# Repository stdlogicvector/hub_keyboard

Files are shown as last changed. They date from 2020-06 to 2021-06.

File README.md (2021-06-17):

# HUB Keyboard

A custom built 80% keyboard with an OLED and an integrated USB hub.

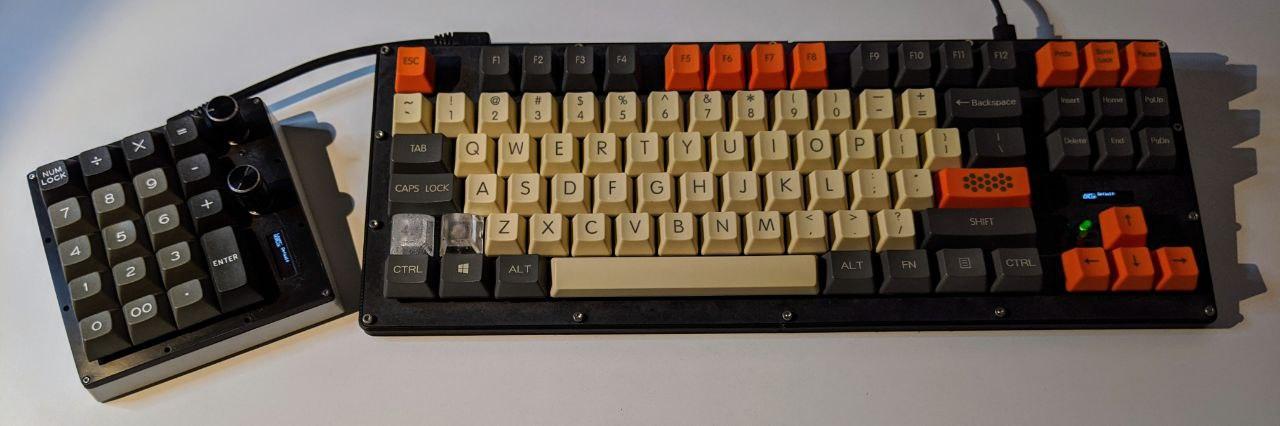
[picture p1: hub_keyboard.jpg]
HUB Keyboard with Numpad attached via USB


(The Numpad can be found here.)

## Circuit Board

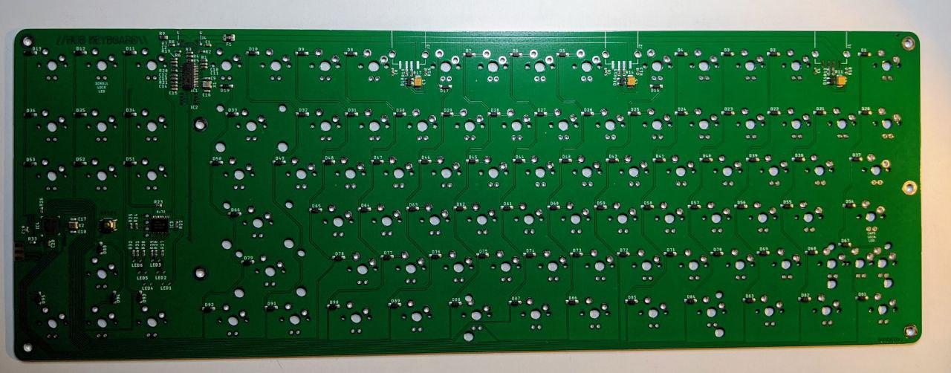
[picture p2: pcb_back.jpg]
Populated Circit Board - Bottom Side


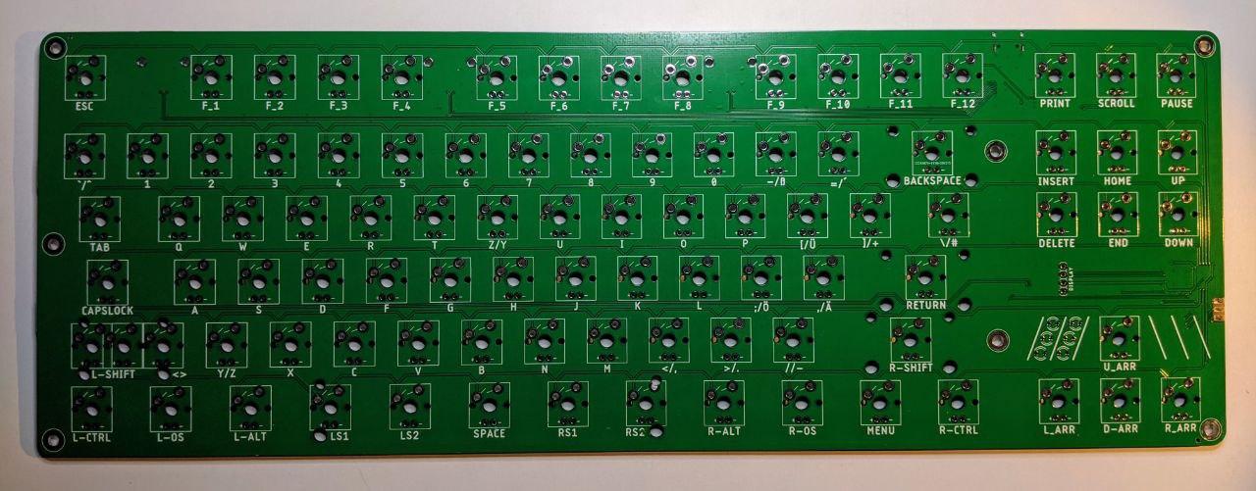
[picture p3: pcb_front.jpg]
Populated Circit Board - Top Side


The circuit board is designed in Eagle.
For easy manufacturing, the gerber-files and SMT production files are included.

The BOM and SMT placement file (CPL) are formatted for use with JLCPCB.

Apart from the keys, display, and the USB-connector all parts can be populated by JLCPCB.
The schematic contains the LCSC partnumbers in the attributes of each part.

### JLCPCB Configuration

If you want to order PCBs from JLC-PCB with the provided gerber-files,
use the following settings after uploading the zipped gerber folder:

* Layers: 2
* Dimension: 362mm x 128.5mm
* PCB Color: Choose what you want
* PCB Thickness: 1.6
* Impedance: no
* Surface Finish: HASL(with lead) (ENIG is also OK)
* Copper Weight: 1
* Gold Fingers: No
* Material Details: FR4-Standard Tg 130-140C
* Panel By JLCPCB: No
* Flying Probe Test: Fully Test
* Castellated Holes: no
* Different Design: 1
* Remove Order Number: Choose what you want

5 PCBs without assembly cost about 17.35€ or $19.60.

If you want to have the SMT parts populated, choose "SMT Assembly" and select "Bottom Layer".

When asked for the BOM and CPL file, upload the provided files.

Assembly and parts for 5 PCBs costs about 45.50€ or $55.90.

### Keys

All keys compatible with Cherry MX 2 or 3 pin should fit the board.
There a mounting holes for the US-layout (with 2.25U Left Shift) and the EU-layout (with <> next to 1.25U Left Shift).
The Spacebar can also be replaced by up 5 individual keys.

### Display

The display is an 0.91" 128x32 SPI OLED module like [this](https://www.ebay.com/itm/312892164528). They are all over ebay and aliexpress.

### Misc Parts

The USB Connectors can be found on Digikey, but you can substitute others with the same pad layout.#

* USB-C : [Digikey](https://www.digikey.com/short/zm17vb)
* USB-A : [Digikey](https://www.digikey.com/short/zm1tcc)

## QMK Configuration

The folder qmk_config contains the configuration and code to build QMK for the HUB-Keyboard.
Just put this folder in qmk/keyboards and run

```
make hub_keyboard/v1:default
```	
	
## Plate & Case

Plate and Case are available as DXF and STL files. The Case also comes in two halves for easier printing. The DXF contains lines for both layout options at the left shift key. Delete what you don't need before cutting.

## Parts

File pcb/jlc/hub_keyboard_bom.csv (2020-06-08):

Comment | Designator | Footprint | LCSC
1.1A | F1 | 1210 | C70100
1M | R8, R10, R13, R16 | 0603 | C22935
1N4148 | D1, D2, D3, D4, D5, D6, D7, D8, D9, D10, D11, D12, D13, D15, D17, D19, D20, D21, D22, D23, D24, D25, D26, D27, D28, D29, D30, D31, D32, D33, D34, D35, D36, D37, D38, D39, D40, D41, D42, D43, D44, D45, D46, D47, D48, D49, D50, D51, D52, D53, D54, D55, D56, D57, D58, D59, D60, D61, D62, D63, D64, D65, D66, D67, D68, D69, D70, D71, D72, D73, D74, D75, D76, D77, D78, D79, D80, D81, D82, D83, D84, D85, D86, D87, D88, D89, D90, D91, D92, D93, D94, D95 | SOD123 | C81598
1k | R22, R23, R26, R27, R28, R29, R30, R31, R32 | 0603 | C21190
1u | C20 | 0603 | C15849
2k7 | R1 | 0603 | C13167
5k1 | R2, R6 | 0603 | C23186
10k | R7, R20, R21, R33 | 0603 | C25804
10n | C14 | 0603 | C57112
10n | C1, C4, C6, C8 | 0603 | C84709
10u | C11, C12, C13 | 0603 | C19702
12MHz | X1 | SMD-3225_4P | C9002
12pF | C9, C16, C17, C18 | 0603 | C38523
16MHz | X2 | SMD-3225_4P | C13738
20k | R5, R24, R25 | 0603 | C4184
22R | R3, R4, R11, R12, R14, R15, R17, R18 | 0603 | C23345
100k | R19 | 0603 | C25803
100nF | C2, C10, C15, C19 | 0603 | C14663
100uF | C3, C5, C7 | 3528 | C16133
FE1.1S | IC1 | SSOP-28 | C9359
Ferrite | R9 | 0805 | C44361
PCF8574APWR | IC3 | TSSOP-20 | C94361
PRTR5V0U2X | D14, D16, D18 | SOT-143 | C384891
ATMEGA32U4-MU | IC4 | QFN-44_EP_7x7x0.5P | C112161
SPST-SMD-5.2 | RESET | SMD-5.2 | C318884
24LC024SN | IC2 | 24LC024SN | C184083

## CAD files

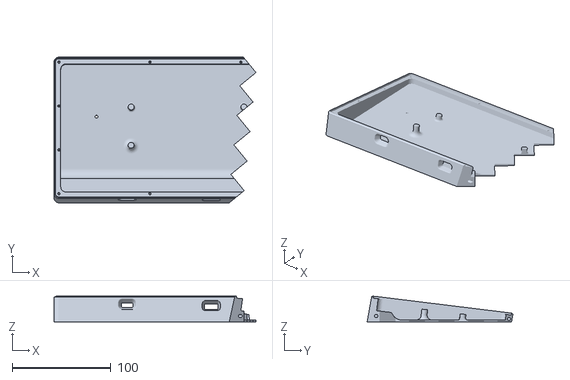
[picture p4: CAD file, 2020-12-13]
cad/Case_3D_right.stl
204.2 x 147.4 x 26.2

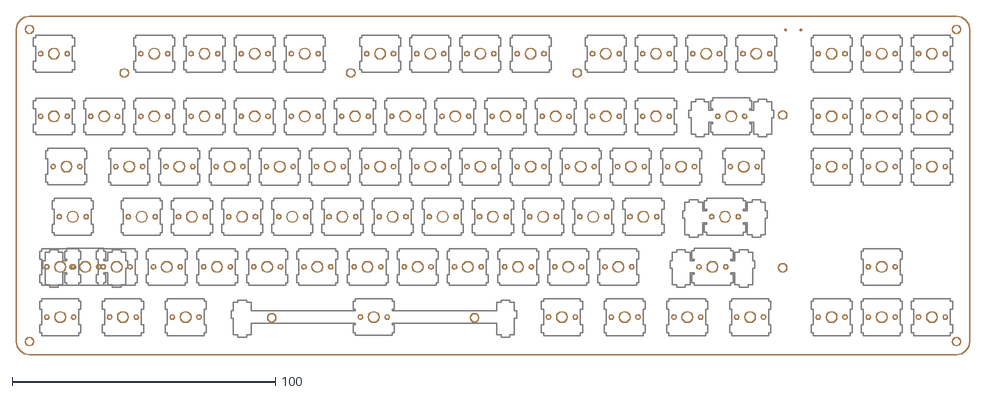
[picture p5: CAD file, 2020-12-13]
cad/keyboard_plate.dxf
362.0 x 128.5

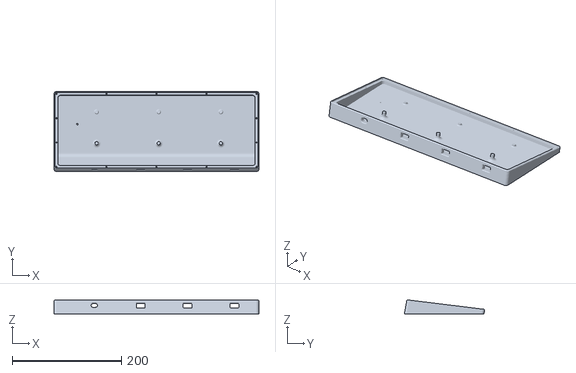
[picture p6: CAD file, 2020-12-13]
cad/Case_3d.stl
376.0 x 147.4 x 26.2

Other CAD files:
cad/Case_3D_left.stl

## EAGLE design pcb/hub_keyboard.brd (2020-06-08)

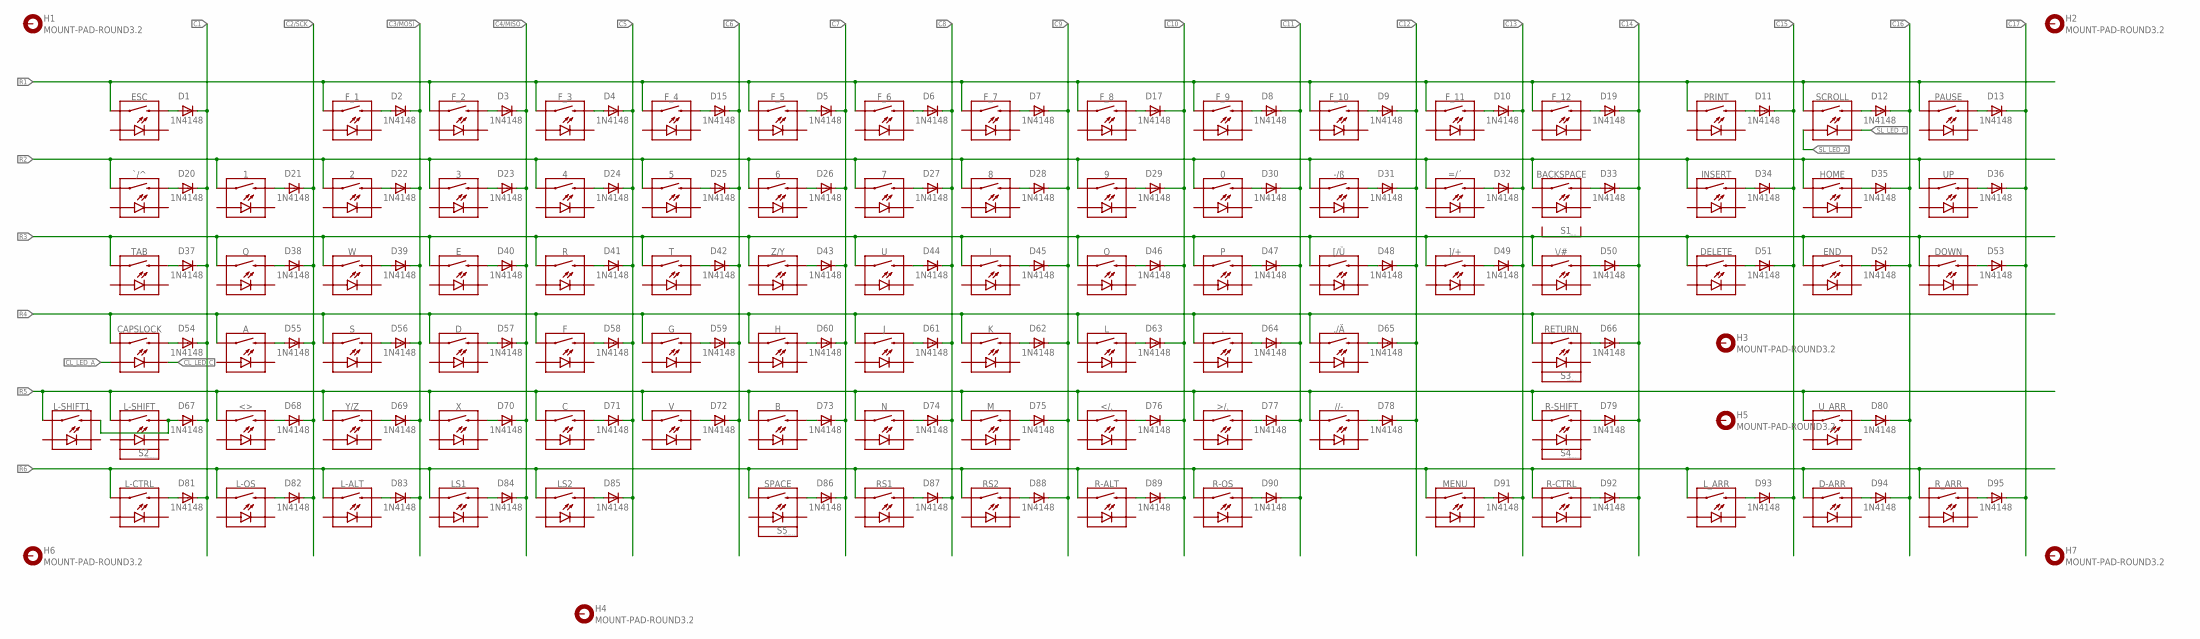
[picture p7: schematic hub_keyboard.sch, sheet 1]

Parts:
0, 1, 2, 3, 4, 5, 6, 7, 8, 9, .: MECHANICAL-KEYBOARD1U; CHERRY-MX-LED-1U
,/Ä: MECHANICAL-KEYBOARD1U; CHERRY-MX-LED-1U
-/ß: MECHANICAL-KEYBOARD1U; CHERRY-MX-LED-1U
//-: MECHANICAL-KEYBOARD1U; CHERRY-MX-LED-1U
</,: MECHANICAL-KEYBOARD1U; CHERRY-MX-LED-1U
<>: MECHANICAL-KEYBOARD1U; CHERRY-MX-LED-1U
=/´: MECHANICAL-KEYBOARD1U; CHERRY-MX-LED-1U
>/.: MECHANICAL-KEYBOARD1U; CHERRY-MX-LED-1U
A: MECHANICAL-KEYBOARD1U; CHERRY-MX-LED-1U
B: MECHANICAL-KEYBOARD1U; CHERRY-MX-LED-1U
BACKSPACE: MECHANICAL-KEYBOARD2U; CHERRY-MX-LED-1X2U
C: MECHANICAL-KEYBOARD1U; CHERRY-MX-LED-1U
CAPSLOCK: MECHANICAL-KEYBOARD1.75U; CHERRY-MX-LED-1.75U
D: MECHANICAL-KEYBOARD1U; CHERRY-MX-LED-1U
D1, D2, D3, D4, D5, D6, D7, D8, D9, D10, D11, D12, D13, D15, D17, D19, D20, D21, D22, D23, D24, D25, D26, D27, D28, D29, D30, D31, D32, D33, D34, D35, D36, D37, D38, D39, D40, D41, D42, D43, D44, D45, D46, D47, D48, D49, D50, D51, D52, D53, D54, D55, D56, D57, D58, D59, D60, D61, D62, D63, D64, D65, D66, D67, D68, D69, D70, D71, D72, D73, D74, D75, D76, D77, D78, D79, D80, D81, D82, D83, D84, D85, D86, D87, D88, D89, D90, D91, D92, D93, D94, D95: 1N4148; SOD123; LCSC C81598
D-ARR: MECHANICAL-KEYBOARD1U; CHERRY-MX-LED-1U
DELETE: MECHANICAL-KEYBOARD1U; CHERRY-MX-LED-1U
DOWN: MECHANICAL-KEYBOARD1U; CHERRY-MX-LED-1U
E: MECHANICAL-KEYBOARD1U; CHERRY-MX-LED-1U
END: MECHANICAL-KEYBOARD1U; CHERRY-MX-LED-1U
ESC: MECHANICAL-KEYBOARD1U; CHERRY-MX-LED-1U
F: MECHANICAL-KEYBOARD1U; CHERRY-MX-LED-1U
F_1, F_2, F_3, F_4, F_5, F_6, F_7, F_8, F_9, F_10, F_11, F_12: MECHANICAL-KEYBOARD1U; CHERRY-MX-LED-1U
G: MECHANICAL-KEYBOARD1U; CHERRY-MX-LED-1U
H: MECHANICAL-KEYBOARD1U; CHERRY-MX-LED-1U
H1, H2, H3, H4, H5, H6, H7: MOUNT-PAD-ROUND3.2; 3,2-PAD
HOME: MECHANICAL-KEYBOARD1U; CHERRY-MX-LED-1U
I: MECHANICAL-KEYBOARD1U; CHERRY-MX-LED-1U
INSERT: MECHANICAL-KEYBOARD1U; CHERRY-MX-LED-1U
J: MECHANICAL-KEYBOARD1U; CHERRY-MX-LED-1U
K: MECHANICAL-KEYBOARD1U; CHERRY-MX-LED-1U
L: MECHANICAL-KEYBOARD1U; CHERRY-MX-LED-1U
L-ALT: MECHANICAL-KEYBOARD1.25U; CHERRY-MX-LED-1.25U
L-CTRL: MECHANICAL-KEYBOARD1.25U; CHERRY-MX-LED-1.25U
L-OS: MECHANICAL-KEYBOARD1.25U; CHERRY-MX-LED-1.25U
L-SHIFT: MECHANICAL-KEYBOARD2.25U; CHERRY-MX-LED-1X2.25
L-SHIFT1: MECHANICAL-KEYBOARD1.25U; CHERRY-MX-LED-1.25U
LS1, LS2: MECHANICAL-KEYBOARD1.25U; CHERRY-MX-LED-1.25U
L_ARR: MECHANICAL-KEYBOARD1U; CHERRY-MX-LED-1U
M: MECHANICAL-KEYBOARD1U; CHERRY-MX-LED-1U
MENU: MECHANICAL-KEYBOARD1.25U; CHERRY-MX-LED-1.25U
N: MECHANICAL-KEYBOARD1U; CHERRY-MX-LED-1U
O: MECHANICAL-KEYBOARD1U; CHERRY-MX-LED-1U
P: MECHANICAL-KEYBOARD1U; CHERRY-MX-LED-1U
PAUSE: MECHANICAL-KEYBOARD1U; CHERRY-MX-LED-1U
PRINT: MECHANICAL-KEYBOARD1U; CHERRY-MX-LED-1U
Q: MECHANICAL-KEYBOARD1U; CHERRY-MX-LED-1U
R: MECHANICAL-KEYBOARD1U; CHERRY-MX-LED-1U
R-ALT: MECHANICAL-KEYBOARD1.25U; CHERRY-MX-LED-1.25U
R-CTRL: MECHANICAL-KEYBOARD1.25U; CHERRY-MX-LED-1.25U
R-OS: MECHANICAL-KEYBOARD1.25U; CHERRY-MX-LED-1.25U
R-SHIFT: MECHANICAL-KEYBOARD2.75U; CHERRY-MX-LED-1X2.75
RETURN: MECHANICAL-KEYBOARD2.25U; CHERRY-MX-LED-1X2.25
RS1, RS2: MECHANICAL-KEYBOARD1.25U; CHERRY-MX-LED-1.25U
R_ARR: MECHANICAL-KEYBOARD1U; CHERRY-MX-LED-1U
S: MECHANICAL-KEYBOARD1U; CHERRY-MX-LED-1U
S1: STABILIZER-1X2U; STABILIZER_1X2U
S2, S3: STABILIZER-1X2.25U; STABILIZER_1X2.25U
S4: STABILIZER-1X2.75U; STABILIZER_1X2.75U
S5: STABILIZER-1X6.25U; STABILIZER_1X6.25U
SCROLL: MECHANICAL-KEYBOARD1U; CHERRY-MX-LED-1U
SPACE: MECHANICAL-KEYBOARD6.25U; CHERRY-MX-LED-1X6.25
T: MECHANICAL-KEYBOARD1U; CHERRY-MX-LED-1U
TAB: MECHANICAL-KEYBOARD1.5U; CHERRY-MX-LED-1.5U
U: MECHANICAL-KEYBOARD1U; CHERRY-MX-LED-1U
UP: MECHANICAL-KEYBOARD1U; CHERRY-MX-LED-1U
U_ARR: MECHANICAL-KEYBOARD1U; CHERRY-MX-LED-1U
V: MECHANICAL-KEYBOARD1U; CHERRY-MX-LED-1U
W: MECHANICAL-KEYBOARD1U; CHERRY-MX-LED-1U
X: MECHANICAL-KEYBOARD1U; CHERRY-MX-LED-1U
Y/Z: MECHANICAL-KEYBOARD1U; CHERRY-MX-LED-1U
Z/Y: MECHANICAL-KEYBOARD1U; CHERRY-MX-LED-1U
[/Ü: MECHANICAL-KEYBOARD1U; CHERRY-MX-LED-1U
\\/#: MECHANICAL-KEYBOARD1.5U; CHERRY-MX-LED-1.5U
]/+: MECHANICAL-KEYBOARD1U; CHERRY-MX-LED-1U
`/^: MECHANICAL-KEYBOARD1U; CHERRY-MX-LED-1U

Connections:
C1: D1.C, D20.C, D37.C, D54.C, D67.C, D81.C; also elsewhere on the board
C2/SCK: D21.C, D38.C, D55.C, D68.C, D82.C; also elsewhere on the board
C3/MOSI: D2.C, D22.C, D39.C, D56.C, D69.C, D83.C; also elsewhere on the board
C4/MISO: D3.C, D23.C, D40.C, D57.C, D70.C, D84.C; also elsewhere on the board
C5: D4.C, D24.C, D41.C, D58.C, D71.C, D85.C; also elsewhere on the board
C6: D15.C, D25.C, D42.C, D59.C, D72.C; also elsewhere on the board
C7: D5.C, D26.C, D43.C, D60.C, D73.C, D86.C; also elsewhere on the board
C8: D6.C, D27.C, D44.C, D61.C, D74.C, D87.C; also elsewhere on the board
C9: D7.C, D28.C, D45.C, D62.C, D75.C, D88.C; also elsewhere on the board
C10: D17.C, D29.C, D46.C, D63.C, D76.C, D89.C; also elsewhere on the board
C11: D8.C, D30.C, D47.C, D64.C, D77.C, D90.C; also elsewhere on the board
C12: D9.C, D31.C, D48.C, D65.C, D78.C; also elsewhere on the board
C13: D10.C, D32.C, D49.C, D91.C; also elsewhere on the board
C14: D19.C, D33.C, D50.C, D66.C, D79.C, D92.C; also elsewhere on the board
C15: D11.C, D34.C, D51.C, D93.C; also elsewhere on the board
C16: D12.C, D35.C, D52.C, D80.C, D94.C; also elsewhere on the board
C17: D13.C, D36.C, D53.C, D95.C; also elsewhere on the board
CL_LED_A: CAPSLOCK.A; also elsewhere on the board
CL_LED_C: CAPSLOCK.K (C); also elsewhere on the board
unnamed: D11.A, PRINT.S2 (2)
unnamed: D34.A, INSERT.S2 (2)
unnamed: D51.A, DELETE.S2 (2)
unnamed: D12.A, SCROLL.S2 (2)
unnamed: D35.A, HOME.S2 (2)
unnamed: D93.A, L_ARR.S2 (2)
unnamed: D52.A, END.S2 (2)
unnamed: D80.A, U_ARR.S2 (2)
unnamed: D94.A, D-ARR.S2 (2)
unnamed: D13.A, PAUSE.S2 (2)
unnamed: D36.A, UP.S2 (2)
unnamed: D53.A, DOWN.S2 (2)
unnamed: <>.S2 (2), D68.A
unnamed: D95.A, R_ARR.S2 (2)
unnamed: D1.A, ESC.S2 (2)
unnamed: D20.A, `/^.S2 (2)
unnamed: D37.A, TAB.S2 (2)
unnamed: CAPSLOCK.S2 (2), D54.A
unnamed: D67.A, L-SHIFT.S2 (2), L-SHIFT1.S2 (2)
unnamed: D81.A, L-CTRL.S2 (2)
unnamed: 1.S2 (2), D21.A
unnamed: D38.A, Q.S2 (2)
unnamed: A.S2 (2), D55.A
unnamed: D69.A, Y/Z.S2 (2)
unnamed: D82.A, L-OS.S2 (2)
unnamed: D2.A, F_1.S2 (2)
unnamed: 2.S2 (2), D22.A
unnamed: D39.A, W.S2 (2)
unnamed: D56.A, S.S2 (2)
unnamed: D70.A, X.S2 (2)
unnamed: D83.A, L-ALT.S2 (2)
unnamed: D3.A, F_2.S2 (2)
unnamed: 3.S2 (2), D23.A
unnamed: D40.A, E.S2 (2)
unnamed: D.S2 (2), D57.A
unnamed: C.S2 (2), D71.A
unnamed: D4.A, F_3.S2 (2)
unnamed: 4.S2 (2), D24.A
unnamed: D41.A, R.S2 (2)
unnamed: D58.A, F.S2 (2)
unnamed: D72.A, V.S2 (2)
unnamed: D15.A, F_4.S2 (2)
unnamed: 5.S2 (2), D25.A
unnamed: D42.A, T.S2 (2)
unnamed: D59.A, G.S2 (2)
unnamed: B.S2 (2), D73.A
unnamed: D86.A, SPACE.S2 (2)
unnamed: D5.A, F_5.S2 (2)
unnamed: 6.S2 (2), D26.A
unnamed: D43.A, Z/Y.S2 (2)
unnamed: D60.A, H.S2 (2)
unnamed: D74.A, N.S2 (2)
unnamed: D6.A, F_6.S2 (2)
unnamed: 7.S2 (2), D27.A
unnamed: D44.A, U.S2 (2)
unnamed: D61.A, J.S2 (2)
unnamed: D75.A, M.S2 (2)
unnamed: D7.A, F_7.S2 (2)
unnamed: 8.S2 (2), D28.A
unnamed: D45.A, I.S2 (2)
unnamed: D62.A, K.S2 (2)
unnamed: </,.S2 (2), D76.A
unnamed: D17.A, F_8.S2 (2)
unnamed: 9.S2 (2), D29.A
unnamed: D46.A, O.S2 (2)
unnamed: D63.A, L.S2 (2)
unnamed: >/..S2 (2), D77.A
unnamed: D89.A, R-ALT.S2 (2)
unnamed: D8.A, F_9.S2 (2)
unnamed: 0.S2 (2), D30.A
unnamed: D47.A, P.S2 (2)
unnamed: ..S2 (2), D64.A
unnamed: //-.S2 (2), D78.A
unnamed: D90.A, R-OS.S2 (2)
unnamed: D9.A, F_10.S2 (2)
unnamed: -/ß.S2 (2), D31.A
unnamed: D48.A, [/Ü.S2 (2)
unnamed: ,/Ä.S2 (2), D65.A
unnamed: D10.A, F_11.S2 (2)
unnamed: =/´.S2 (2), D32.A
unnamed: D49.A, ]/+.S2 (2)
unnamed: D91.A, MENU.S2 (2)
unnamed: D19.A, F_12.S2 (2)
unnamed: BACKSPACE.S2 (2), D33.A
unnamed: D50.A, \\/#.S2 (2)
unnamed: D66.A, RETURN.S2 (2)
unnamed: D79.A, R-SHIFT.S2 (2)
unnamed: D92.A, R-CTRL.S2 (2)
unnamed: D85.A, LS2.S2 (2)
unnamed: D84.A, LS1.S2 (2)
unnamed: D88.A, RS2.S2 (2)
unnamed: D87.A, RS1.S2 (2)
R1: ESC.S1 (1), F_1.S1 (1), F_2.S1 (1), F_3.S1 (1), F_4.S1 (1), F_5.S1 (1), F_6.S1 (1), F_7.S1 (1), F_8.S1 (1), F_9.S1 (1), F_10.S1 (1), F_11.S1 (1), F_12.S1 (1), PAUSE.S1 (1), PRINT.S1 (1), SCROLL.S1 (1); also elsewhere on the board
R2: 0.S1 (1), 1.S1 (1), 2.S1 (1), 3.S1 (1), 4.S1 (1), 5.S1 (1), 6.S1 (1), 7.S1 (1), 8.S1 (1), 9.S1 (1), -/ß.S1 (1), =/´.S1 (1), BACKSPACE.S1 (1), HOME.S1 (1), INSERT.S1 (1), UP.S1 (1), `/^.S1 (1); also elsewhere on the board
R3: DELETE.S1 (1), DOWN.S1 (1), E.S1 (1), END.S1 (1), I.S1 (1), O.S1 (1), P.S1 (1), Q.S1 (1), R.S1 (1), T.S1 (1), TAB.S1 (1), U.S1 (1), W.S1 (1), Z/Y.S1 (1), [/Ü.S1 (1), \\/#.S1 (1), ]/+.S1 (1); also elsewhere on the board
R4: ,/Ä.S1 (1), ..S1 (1), A.S1 (1), CAPSLOCK.S1 (1), D.S1 (1), F.S1 (1), G.S1 (1), H.S1 (1), J.S1 (1), K.S1 (1), L.S1 (1), RETURN.S1 (1), S.S1 (1); also elsewhere on the board
R5: //-.S1 (1), </,.S1 (1), <>.S1 (1), >/..S1 (1), B.S1 (1), C.S1 (1), L-SHIFT.S1 (1), L-SHIFT1.S1 (1), M.S1 (1), N.S1 (1), R-SHIFT.S1 (1), U_ARR.S1 (1), V.S1 (1), X.S1 (1), Y/Z.S1 (1); also elsewhere on the board
R6: D-ARR.S1 (1), L-ALT.S1 (1), L-CTRL.S1 (1), L-OS.S1 (1), LS1.S1 (1), LS2.S1 (1), L_ARR.S1 (1), MENU.S1 (1), R-ALT.S1 (1), R-CTRL.S1 (1), R-OS.S1 (1), RS1.S1 (1), RS2.S1 (1), R_ARR.S1 (1), SPACE.S1 (1); also elsewhere on the board
SL_LED_A: SCROLL.A; also elsewhere on the board
SL_LED_C: SCROLL.K (C); also elsewhere on the board

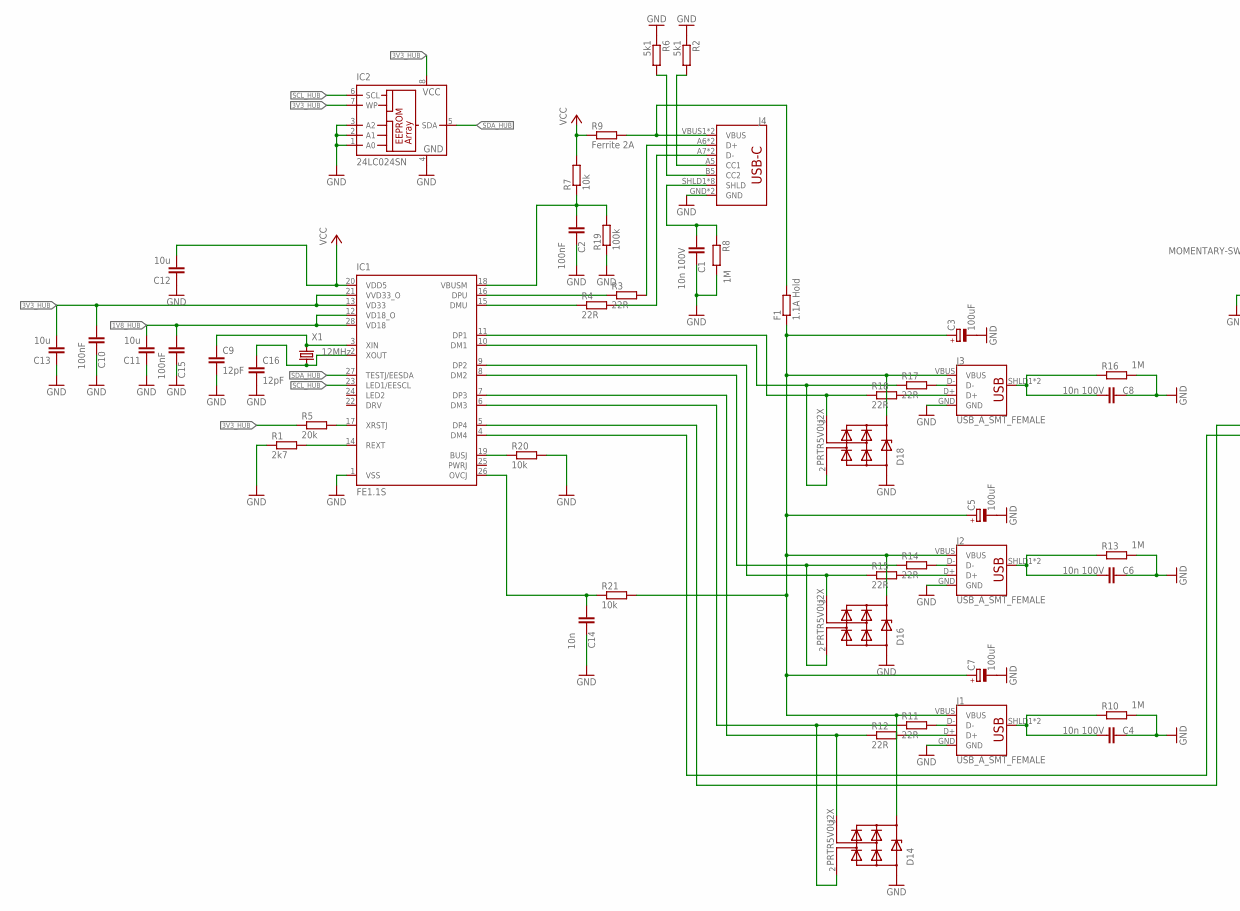
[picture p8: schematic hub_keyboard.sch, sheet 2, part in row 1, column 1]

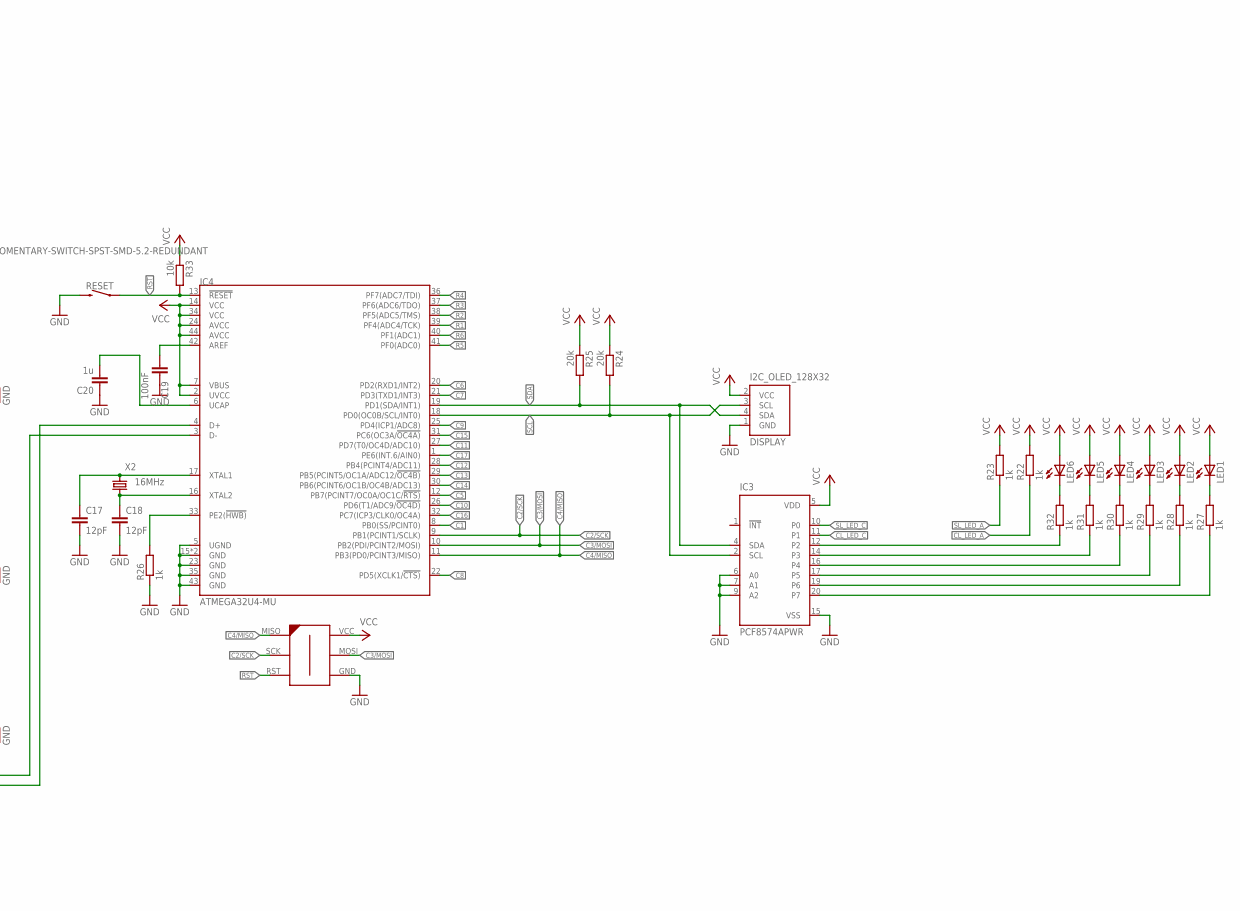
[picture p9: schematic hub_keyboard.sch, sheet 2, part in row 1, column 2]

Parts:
C1, C4, C6, C8: 10n 100V; C0603; LCSC C84709
C2, C10, C15, C19: 100nF; C0603; LCSC C14663
C3, C5, C7: 100uF; CT3528; LCSC C16133
C9, C16, C17, C18: 12pF; C0603; LCSC C38523
C11, C12, C13: 10u; C0603; LCSC C19702
C14: 10n; C0603; LCSC C57112
C20: 1u; C0603; LCSC C15849
D14, D16, D18: PRTR5V0U2X; SOT143; DIGIKEY 1727-3884-1-ND
DISPLAY: I2C_OLED_128X32; 128X32_I2C_OLED
F1: 1.1A Hold; R1210; LCSC C70100
IC1: FE1.1S; SSOP28; LCSC C9359
IC2: 24LC024SN; SO-08; LCSC C184083
IC3: PCF8574APWR; SSOP20; LCSC C94361
IC4: ATMEGA32U4-MU; QFN44G-0.5-7X7MM; LCSC C112161
ISP: AVR-ISP-6-EDGE; 6PAD_ISP
J1, J2, J3: USB_A_SMT_FEMALE; USB-A-S-SILK-FEMALE; DIGIKEY 609-4946-1-ND
J4: USB_C2-LAYER; USB-C-16P; DIGIKEY 2073-USB4105-GF-ACT-ND
LED1, LED2, LED3, LED4, LED5, LED6: LED3MM
R1: 2k7; R0603; LCSC C13167
R2, R6: 5k1; R0603; LCSC C23186
R3, R4, R11, R12, R14, R15, R17, R18: 22R; R0603; LCSC C23345
R5, R24, R25: 20k; R0603; LCSC C4184
R7, R20, R21, R33: 10k; R0603; LCSC C25804
R8, R10, R13, R16: 1M; R0603; LCSC C22935
R9: Ferrite 2A; R0805; LCSC C44361
R19: 100k; R0603; LCSC C25803
R22, R23, R26, R27, R28, R29, R30, R31, R32: 1k; R0603; LCSC C21190
RESET: MOMENTARY-SWITCH-SPST-SMD-5.2-REDUNDANT; TACTILE_SWITCH_SMD_5.2MM; LCSC C318884
X1: 12MHz; 3.2X2.5_KX-7; LCSC C9002
X2: 16MHz; 3.2X2.5_KX-7; LCSC C13738

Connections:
1V8_HUB: C11.2, C15.2, IC1.12 (VD18_O), IC1.28 (VD18)
3V3_HUB: C10.2, C13.2, IC1.13 (VD33), IC1.21 (VVD33_O), IC2.7 (WP), IC2.8 (VCC), R5.1
C1: IC4.8 (PB0(SS/PCINT0)); also elsewhere on the board
C2/SCK: IC4.9 (PB1(PCINT1/SCLK)), ISP.SCK; also elsewhere on the board
C3/MOSI: IC4.10 (PB2(PDI/PCINT2/MOSI)), ISP.MOSI; also elsewhere on the board
C4/MISO: IC4.11 (PB3(PD0/PCINT3/MISO)), ISP.MISO; also elsewhere on the board
C5: IC4.12 (PB7(PCINT7/OC0A/OC1C/!RTS)); also elsewhere on the board
C6: IC4.20 (PD2(RXD1/INT2)); also elsewhere on the board
C7: IC4.21 (PD3(TXD1/INT3)); also elsewhere on the board
C8: IC4.22 (PD5(XCLK1/!CTS)); also elsewhere on the board
C9: IC4.25 (PD4(ICP1/ADC8)); also elsewhere on the board
C10: IC4.26 (PD6(T1/ADC9/!OC4D)); also elsewhere on the board
C11: IC4.27 (PD7(T0/OC4D/ADC10)); also elsewhere on the board
C12: IC4.28 (PB4(PCINT4/ADC11)); also elsewhere on the board
C13: IC4.29 (PB5(PCINT5/OC1A/ADC12/!OC4B)); also elsewhere on the board
C14: IC4.30 (PB6(PCINT6/OC1B/OC4B/ADC13)); also elsewhere on the board
C15: IC4.31 (PC6(OC3A/!OC4A)); also elsewhere on the board
C16: IC4.32 (PC7(ICP3/CLK0/OC4A)); also elsewhere on the board
C17: IC4.1 (PE6(INT.6/AIN0)); also elsewhere on the board
CL_LED_A: R22.1; also elsewhere on the board
CL_LED_C: IC3.11 (P1); also elsewhere on the board
GND: C1.1, C2.1, C3.-, C4.1, C5.-, C6.1, C7.-, C8.1, C9.2, C10.1, C11.1, C12.1, C13.1, C14.1, C15.1, C16.2, C17.2, C18.2, C19.1, C20.1, D14.1 (GND), D16.1 (GND), D18.1 (GND), DISPLAY.1 (GND), IC1.1 (VSS), IC2.1 (A0), IC2.2 (A1), IC2.3 (A2), IC2.4 (GND), IC3.6 (A0), IC3.7 (A1), IC3.9 (A2), IC3.15 (VSS), IC4.5 (UGND), IC4.15 (GND), IC4.23 (GND), IC4.35 (GND), IC4.43 (GND), IC4.TAB (GND), ISP.GND, J1.GND, J2.GND, J3.GND, J4.GND, J4.GND2 (GND), R1.1, R2.1, R6.1, R8.2, R10.2, R13.2, R16.2, R19.1, R20.2, R26.1, RESET.3 (2), RESET.4 (2)
unnamed: IC4.33 (PE2(!HWB)), R26.2
unnamed: IC1.17 (XRSTJ), R5.2
unnamed: IC1.14 (REXT), R1.2
unnamed: IC1.19 (BUSJ), R20.1
unnamed: J4.A5 (CC1), R2.2
unnamed: C3.+, C5.+, C7.+, D14.4 (VCC), D16.4 (VCC), D18.4 (VCC), F1.1, J1.VBUS, J2.VBUS, J3.VBUS, R21.2
unnamed: C14.2, IC1.26 (OVCJ), R21.1
unnamed: F1.2, J4.VBUS1 (VBUS), J4.VBUS2 (VBUS), R9.2
unnamed: D16.2 (IO1), IC1.8 (DM2), R14.1
unnamed: D16.3 (IO2), IC1.9 (DP2), R15.1
unnamed: D14.3 (IO2), IC1.7 (DP3), R12.1
unnamed: D14.2 (IO1), IC1.6 (DM3), R11.1
unnamed: J4.A7 (D-), J4.B7 (D-), R4.2
unnamed: J4.A6 (D+), J4.B6 (D+), R3.2
unnamed: C9.1, IC1.3 (XIN), X1.3 (2)
unnamed: IC1.15 (DMU), R4.1
unnamed: IC1.16 (DPU), R3.1
unnamed: IC1.4 (DM4), IC4.3 (D-)
unnamed: IC1.5 (DP4), IC4.4 (D+)
unnamed: C2.2, IC1.18 (VBUSM), R7.1, R19.2
unnamed: C17.1, IC4.17 (XTAL1), X2.3 (2)
unnamed: C18.1, IC4.16 (XTAL2), X2.1
unnamed: C20.2, IC4.6 (UCAP)
unnamed: C8.2, J3.SHLD1 (SHIELD), J3.SHLD2 (SHIELD), R16.1
unnamed: C6.2, J2.SHLD1 (SHIELD), J2.SHLD2 (SHIELD), R13.1
unnamed: C4.2, J1.SHLD1 (SHIELD), J1.SHLD2 (SHIELD), R10.1
unnamed: C1.2, J4.SHLD1 (SHLD), J4.SHLD2 (SHLD), J4.SHLD3 (SHLD), J4.SHLD4 (SHLD), J4.SHLD5 (SHLD), J4.SHLD6 (SHLD), J4.SHLD7 (SHLD), J4.SHLD8 (SHLD), R8.1
unnamed: J4.B5 (CC2), R6.2
unnamed: C19.2, IC4.42 (AREF)
unnamed: C16.1, IC1.2 (XOUT), X1.1
unnamed: LED6.K (C), R32.2
unnamed: LED5.K (C), R31.2
unnamed: LED4.K (C), R30.2
unnamed: LED3.K (C), R29.2
unnamed: LED2.K (C), R28.2
unnamed: LED1.K (C), R27.2
unnamed: IC3.12 (P2), R32.1
unnamed: IC3.14 (P3), R31.1
unnamed: IC3.16 (P4), R30.1
unnamed: IC3.17 (P5), R29.1
unnamed: IC3.19 (P6), R28.1
unnamed: IC3.20 (P7), R27.1
unnamed: J3.D-, R17.2
unnamed: J3.D+, R18.2
unnamed: J2.D-, R14.2
unnamed: J2.D+, R15.2
unnamed: J1.D-, R11.2
unnamed: J1.D+, R12.2
R1: IC4.39 (PF4(ADC4/TCK)); also elsewhere on the board
R2: IC4.38 (PF5(ADC5/TMS)); also elsewhere on the board
R3: IC4.37 (PF6(ADC6/TDO)); also elsewhere on the board
R4: IC4.36 (PF7(ADC7/TDI)); also elsewhere on the board
R5: IC4.41 (PF0(ADC0)); also elsewhere on the board
R6: IC4.40 (PF1(ADC1)); also elsewhere on the board
RST: IC4.13 (!RESET), ISP.RST, R33.2, RESET.1, RESET.2 (1)
SCL: DISPLAY.3 (SCL), IC3.2 (SCL), IC4.18 (PD0(OC0B/SCL/INT0)), R24.2
SCL_HUB: IC1.23 (LED1/EESCL), IC2.6 (SCL)
SDA: DISPLAY.4 (SDA), IC3.4 (SDA), IC4.19 (PD1(SDA/INT1)), R25.2
SDA_HUB: IC1.27 (TESTJ/EESDA), IC2.5 (SDA)
SL_LED_A: R23.1; also elsewhere on the board
SL_LED_C: IC3.10 (P0); also elsewhere on the board
USB1N: D18.2 (IO1), IC1.10 (DM1), R17.1
USB1P: D18.3 (IO2), IC1.11 (DP1), R18.1
VCC: C12.2, DISPLAY.2 (VCC), IC1.20 (VDD5), IC3.5 (VDD), IC4.2 (UVCC), IC4.7 (VBUS), IC4.14 (VCC), IC4.24 (AVCC), IC4.34 (VCC), IC4.44 (AVCC), ISP.VCC, LED1.A, LED2.A, LED3.A, LED4.A, LED5.A, LED6.A, R7.2, R9.1, R22.2, R23.2, R24.1, R25.1, R33.1

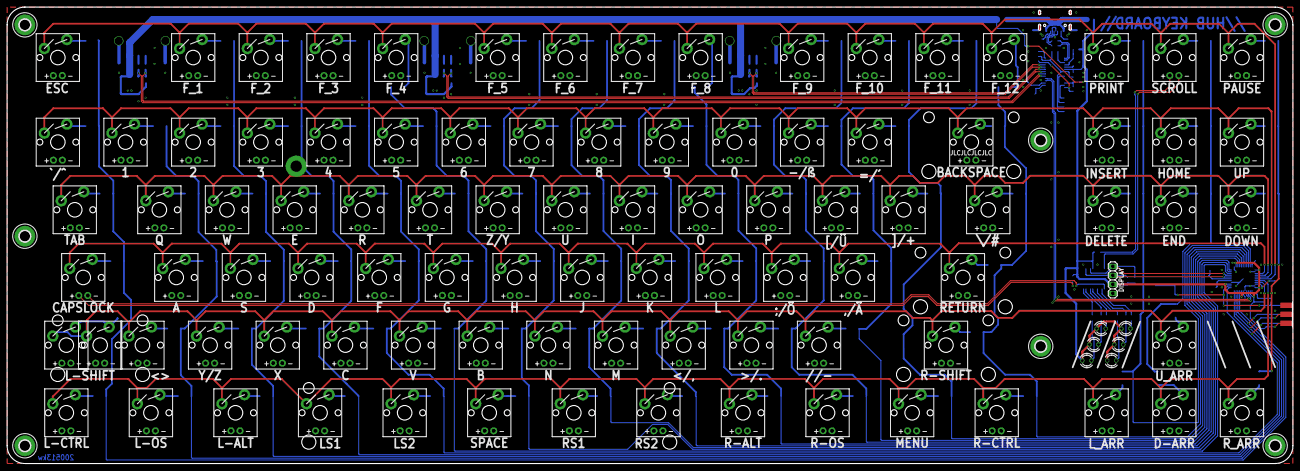
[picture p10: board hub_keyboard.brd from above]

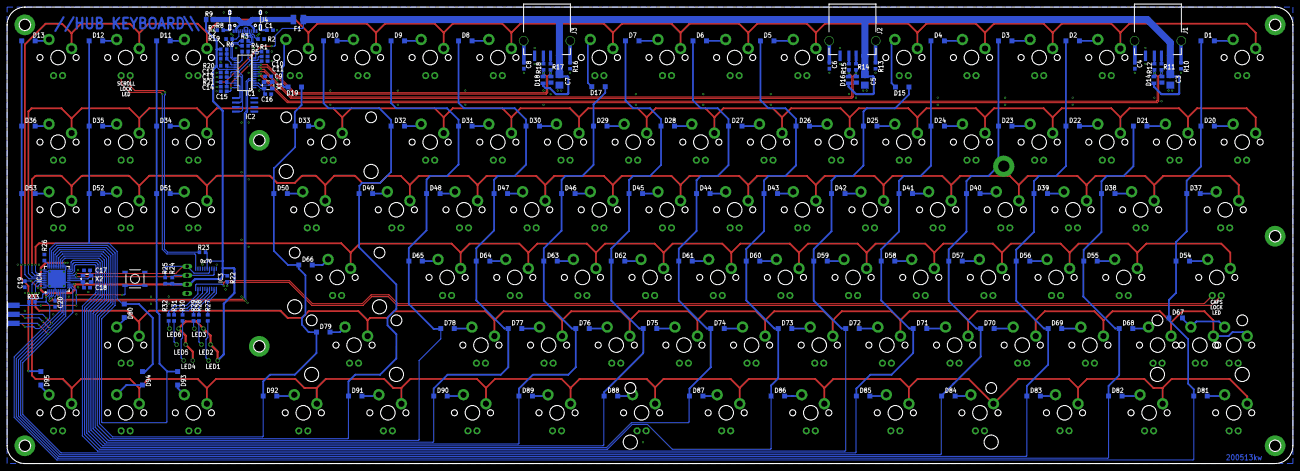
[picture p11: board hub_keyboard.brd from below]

Board: 2 copper layers, 362.0 x 128.5 mm, 273 parts (161 on the bottom side), 178 nets.

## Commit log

2020-06-08 Added Gerbers
    [hub_keyboard.GBL, hub_keyboard.GBO, hub_keyboard.GBP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]
2020-12-13 Added Case & Plate files
    CAD files for a case and a plate. The case is also available as two halves for easier printing.
    [Case_3D_left.stl, Case_3D_right.stl, Case_3d.stl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]

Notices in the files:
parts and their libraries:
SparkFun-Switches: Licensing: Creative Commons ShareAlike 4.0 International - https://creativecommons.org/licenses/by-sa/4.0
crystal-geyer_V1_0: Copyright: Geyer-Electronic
